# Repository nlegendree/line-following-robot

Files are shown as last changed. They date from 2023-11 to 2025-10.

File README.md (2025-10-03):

# Line Following Robot 🤖

<div align="center">

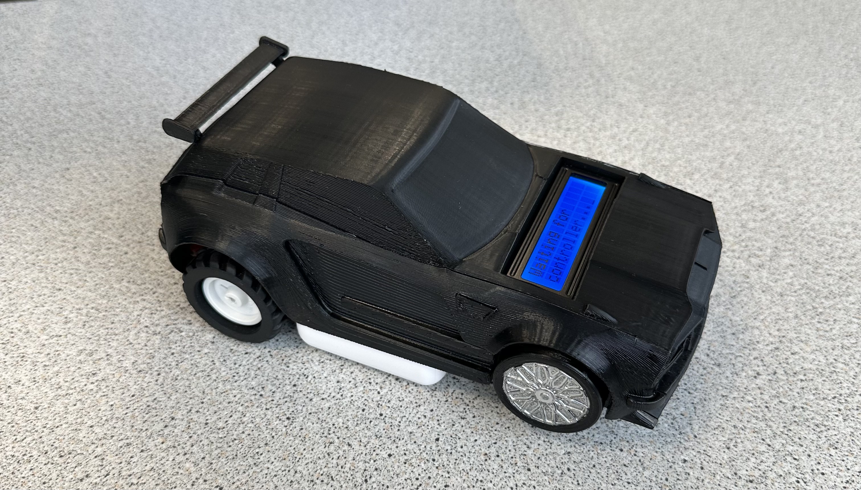
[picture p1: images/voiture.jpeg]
Robot


**Autonomous line-following robot with obstacle detection and PS5 controller support**





*INSA Rouen Normandie - Embedded Electronics Project 2023-2024*

</div>

## 📋 Table of Contents

- [About](#-about)
- [Features](#-features)
- [Hardware Components](#-hardware-components)
- [Circuit Diagram](#-circuit-diagram)
- [Software Architecture](#-software-architecture)
- [Installation](#-installation)
- [Usage](#-usage)
- [Project Structure](#-project-structure)
- [Team](#-team)

## 🎯 About

This project is an autonomous line-following robot developed as part of the **Embedded Electronics Systems** course at INSA Rouen Normandie. The robot combines infrared line detection, ultrasonic obstacle avoidance, and manual control via a PS5 controller, all housed in a custom 3D-printed Rocket League-inspired chassis.

### Key Highlights

- **Dual Control Modes**: Autonomous line-following and manual PS5 controller
- **Safety Features**: Ultrasonic distance sensor with buzzer alerts
- **Real-time Display**: LCD screen showing status and distance information
- **Custom Hardware**: 3D-printed car body designed in SolidWorks
- **Low-level Programming**: Written entirely in C using WiringPi library

## ✨ Features

### Autonomous Mode
- ✅ **Line Following**: Three TCRT5000 infrared sensors for precise line tracking
- ✅ **Intersection Detection**: Recognizes and handles T-junctions and crossroads
- ✅ **Obstacle Detection**: HC-SR04 ultrasonic sensor with 20cm stop threshold
- ✅ **Audio Alerts**: Active buzzer for obstacle warnings
- ✅ **Visual Feedback**: LCD display showing movement status and distance

### Manual Control Mode
- 🎮 **PS5 Controller Support**: Full gamepad integration via SDL2
- 🚗 **Analog Control**: Smooth acceleration and steering using triggers and joystick
- 📊 **Speed Display**: Real-time speed indicator on LCD screen
- 🔄 **Mode Switching**: Instant toggle between autonomous and manual modes

## 🔧 Hardware Components

| Component | Model | Function |
|---|---|---|
| **Microcontroller** | Raspberry Pi 4 | Main control unit |
| **Line Sensors** | TCRT5000 (×3) | Infrared line detection |
| **Distance Sensor** | HC-SR04 | Ultrasonic obstacle detection |
| **Motor Driver** | L293D | Dual H-bridge motor controller |
| **Display** | LCD 1602 I2C | Status and distance display |
| **Buzzer** | Active Buzzer | Obstacle alert |
| **Controller** | PS5 DualSense | Manual control (Bluetooth) |
| **Motors** | DC Motors (×2) | Wheel propulsion |
| **Power** | 9V Battery + External Pack | Raspberry Pi and motors |

### Component Images

<details>
<summary>View Hardware Components</summary>

<table>
<tr>
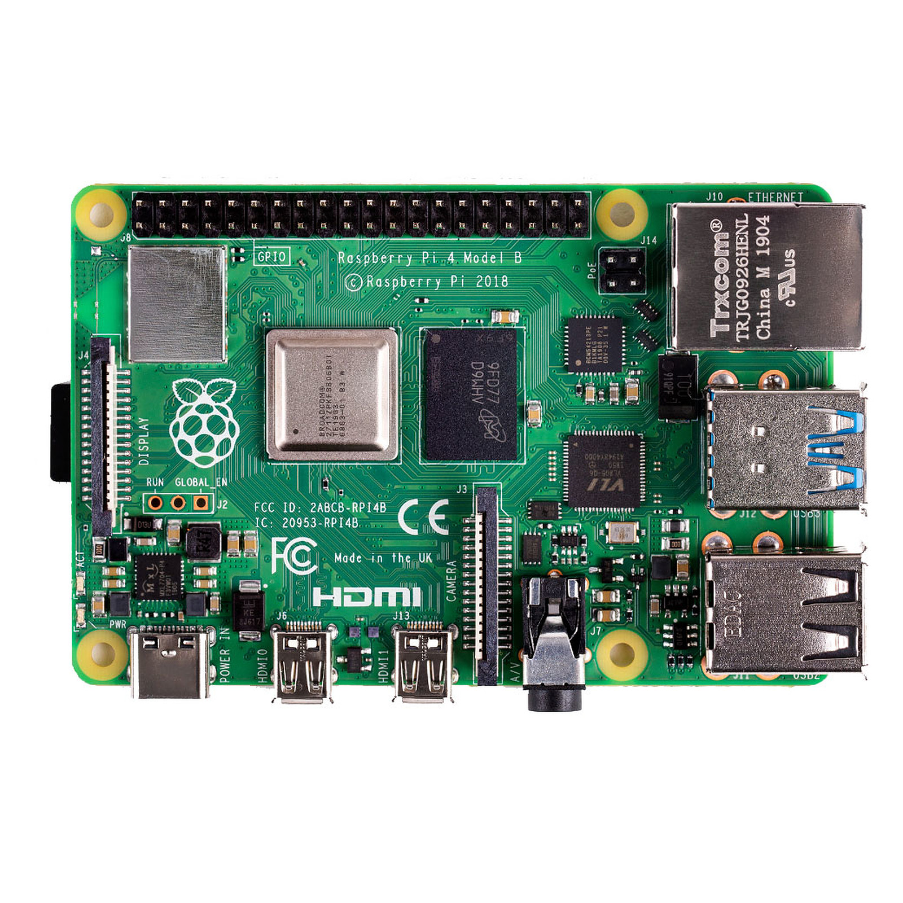
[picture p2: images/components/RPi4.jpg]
<td><br/><b>Raspberry Pi 4</b></td>
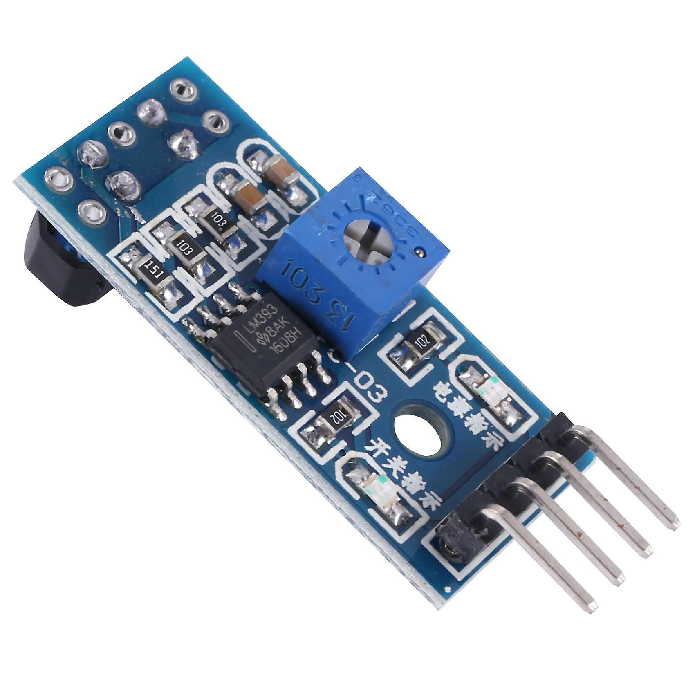
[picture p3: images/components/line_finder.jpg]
<td><br/><b>TCRT5000 Sensor</b></td>
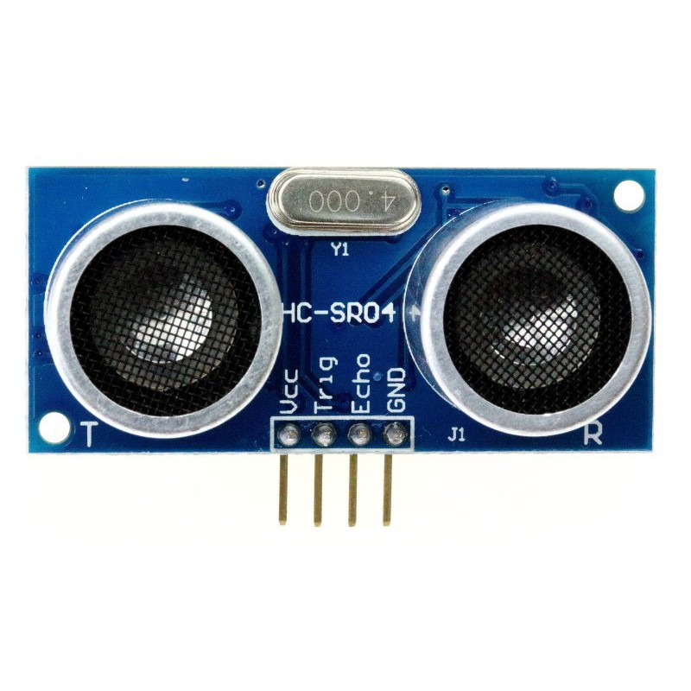
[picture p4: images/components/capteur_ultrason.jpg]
<td><br/><b>HC-SR04</b></td>
</tr>
<tr>
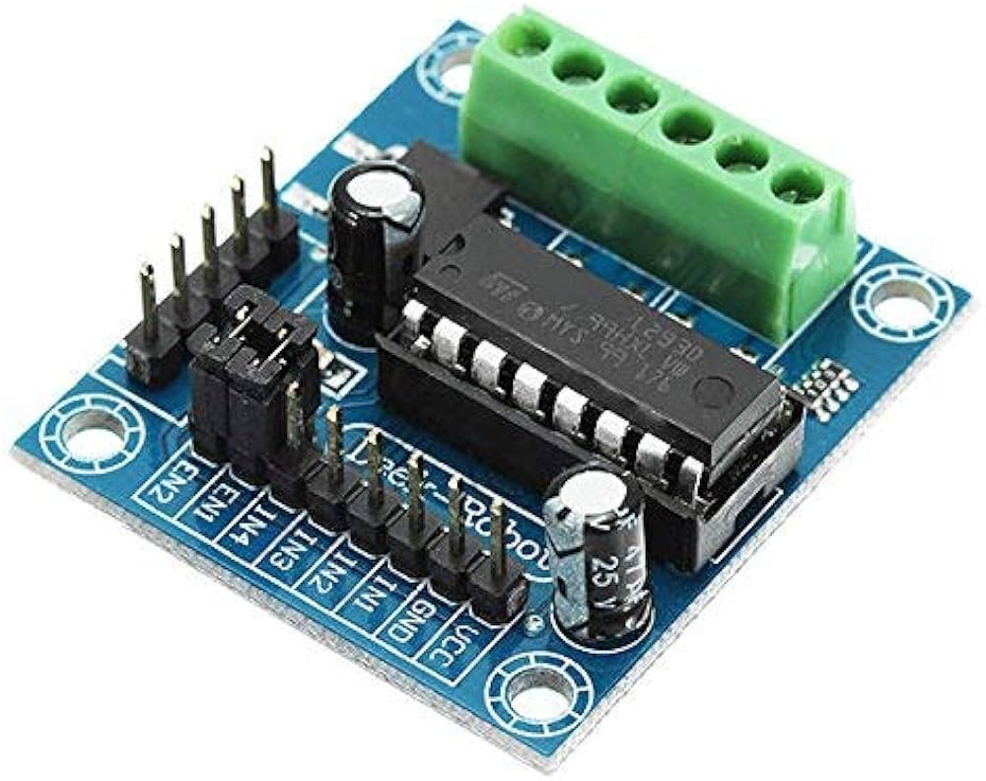
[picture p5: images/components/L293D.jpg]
<td><br/><b>L293D Driver</b></td>
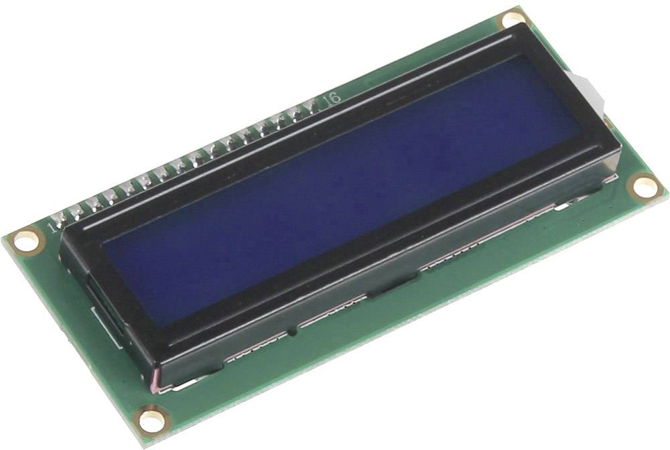
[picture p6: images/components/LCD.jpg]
<td><br/><b>LCD 1602</b></td>
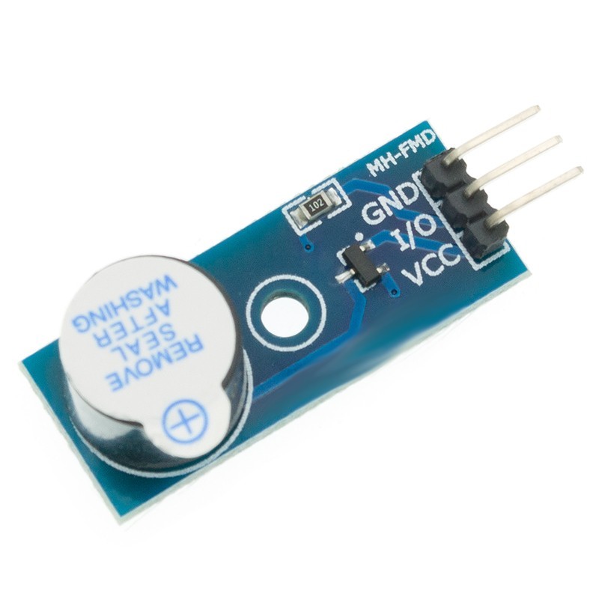
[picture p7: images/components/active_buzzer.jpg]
<td><br/><b>Active Buzzer</b></td>
</tr>
</table>

</details>

## 📐 Circuit Diagram

The complete circuit was designed using **Fritzing** and includes GPIO pin mappings for all components.

<details>
<summary>View Circuit Schematics</summary>

### Component Layout
Fritzing Diagram

### Electronic Schematic
Electronic Schematic

</details>

### GPIO Pin Configuration

```c
// Line Finder Sensors
#define PIN_LINEFINDER_LEFT    17
#define PIN_LINEFINDER_CENTER  22
#define PIN_LINEFINDER_RIGHT   10

// Ultrasonic Sensor
#define PIN_TRIG  25
#define PIN_ECHO  8

// Motor Driver (L293D)
#define PIN_EN1   13  // PWM Enable Motor 1
#define PIN_EN2   12  // PWM Enable Motor 2
#define PIN_M1A   5   // Motor 1 Direction A
#define PIN_M1B   6   // Motor 1 Direction B
#define PIN_M2A   26  // Motor 2 Direction A
#define PIN_M2B   21  // Motor 2 Direction B

// Buzzer
#define PIN_BUZZER 14
```

## 🏗️ Software Architecture

The project is structured using a modular approach with separate modules for each hardware component.

### Code Organization

```
src/
├── main.c           # Main program with event loop
├── motors.c         # Motor control (PWM, direction)
├── lineFinder.c     # Line detection logic
├── distance.c       # Ultrasonic sensor readings
├── controller.c     # PS5 gamepad handling (SDL2)
├── i2cLCD.c        # LCD display communication
└── buzzer.c        # Buzzer control

include/
├── motors.h
├── lineFinder.h
├── distance.h
├── controller.h
├── i2cLCD.h
├── buzzer.h
└── gpioPins.h      # GPIO pin definitions
```

### Key Algorithms

#### Line Following Logic

```c
// Truth table for line following
// L | C | R | Action
// --+---+---+------------------
// 0 | 0 | 0 | Keep previous state
// 0 | 0 | 1 | Turn right
// 0 | 1 | 0 | Move forward
// 0 | 1 | 1 | Move forward (intersection)
// 1 | 0 | 0 | Turn left
// 1 | 0 | 1 | Move forward (intersection)
// 1 | 1 | 0 | Move forward (intersection)
// 1 | 1 | 1 | Move forward (intersection)
```

#### PWM Motor Control

The robot uses hardware PWM with adaptive speed control based on steering angle:

```c
// Speed adjustment for turning
if (angle < 0) {  // Turning left
    leftMotorSpeed = baseSpeed * (1 - |angle| / MAX_ANGLE);
    rightMotorSpeed = baseSpeed;
} else {  // Turning right
    leftMotorSpeed = baseSpeed;
    rightMotorSpeed = baseSpeed * (1 - angle / MAX_ANGLE);
}
```

## 🚀 Installation

### Prerequisites

```bash
# Update system
sudo apt update && sudo apt upgrade

# Install required libraries
sudo apt install -y \
    build-essential \
    git \
    wiringpi \
    libsdl2-dev \
    libi2c-dev

# Enable I2C interface
sudo raspi-config
# Navigate to: Interfacing Options → I2C → Enable
```

### Building the Project

```bash
# Clone the repository
git clone git@github.com:nlegendree/line-following-robot.git
cd line-following-robot

# Compile the project
make

# The executable will be created in bin/rc
```

### Hardware Setup

1. **Connect all components** according to the Fritzing diagram
2. **Pair PS5 controller** via Bluetooth settings
3. **Calibrate line sensors** on your track surface
4. **Test motors** individually before full assembly

## 📖 Usage

### Running the Robot

```bash
# Start the program (requires sudo for GPIO access)
sudo ./bin/rc
```

### Controls

#### Autonomous Mode
- Press **Cross (×)** button to activate line-following mode
- The robot will:
  - Follow black lines automatically
  - Stop when obstacles are < 20cm away
  - Display distance on LCD when obstacles are detected
  - Sound buzzer for close obstacles

#### Manual Mode
- Press **Circle (○)** button to activate manual control
- **R2 Trigger**: Accelerate forward
- **L2 Trigger**: Reverse
- **Left Stick (horizontal)**: Steering
- **LCD Display**: Shows current speed

### Mode Indicators

| LCD Display | Meaning |
|---|---|
| `Waiting for controller...` | No controller connected |
| `Speed: XX kph` | Manual mode active |
| `Moving forward` | Line-following: going straight |
| `Turning left/right` | Line-following: adjusting direction |
| `Obstacle: XX cm` | Warning distance display |
| `Obstacle too close!` | Emergency stop (< 20cm) |

## 📁 Project Structure

```
line-following-robot/
├── bin/                    # Compiled executables
├── src/                    # C source files
│   ├── main.c
│   ├── motors.c
│   ├── lineFinder.c
│   ├── distance.c
│   ├── controller.c
│   ├── i2cLCD.c
│   └── buzzer.c
├── include/                # Header files
│   ├── motors.h
│   ├── lineFinder.h
│   ├── distance.h
│   ├── controller.h
│   ├── i2cLCD.h
│   ├── buzzer.h
│   └── gpioPins.h
├── images/                 # Project images
│   ├── components/        # Component photos
│   ├── fritzing/          # Circuit diagrams (PDF)
│   ├── solidworks/        # 3D model screenshots
│   └── voiture.jpeg       # Final robot photo
├── circuit/               # Fritzing project files
├── makefile              # Build configuration
├── LICENSE               # MIT License
└── README.md             # This file
```

## 👥 Team

This project was developed collaboratively by a **team of four engineering students** at INSA Rouen Normandie as part of the Embedded Electronics Systems course.

**Academic Year**: 2023-2024
**Institution**: [INSA Rouen Normandie](https://www.insa-rouen.fr/)

## 📄 License

This project is available under the MIT License. See [LICENSE](LICENSE) for details.

---

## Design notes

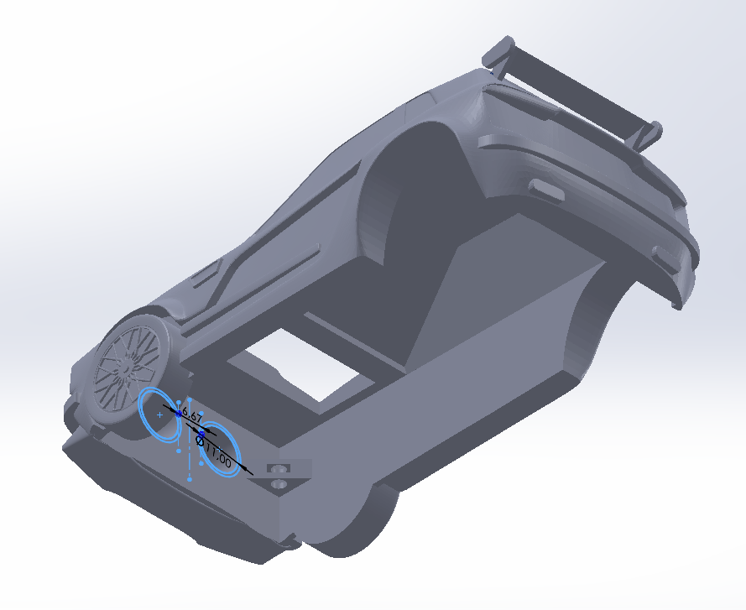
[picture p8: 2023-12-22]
images/solidworks/solidworks4.png

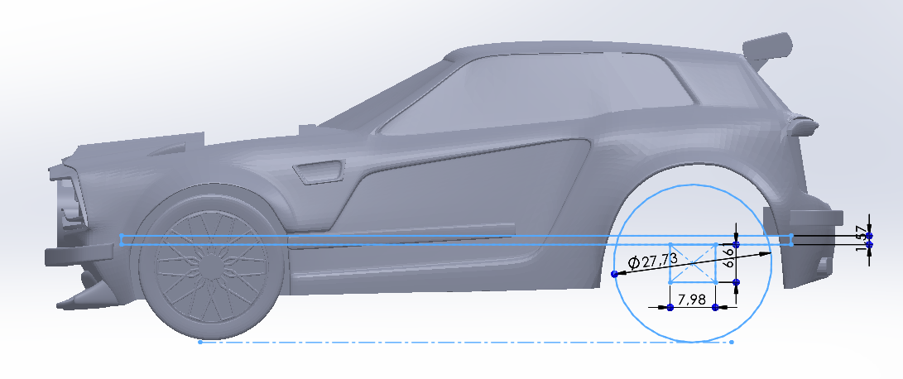
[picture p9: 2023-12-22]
images/solidworks/solidworks3.png

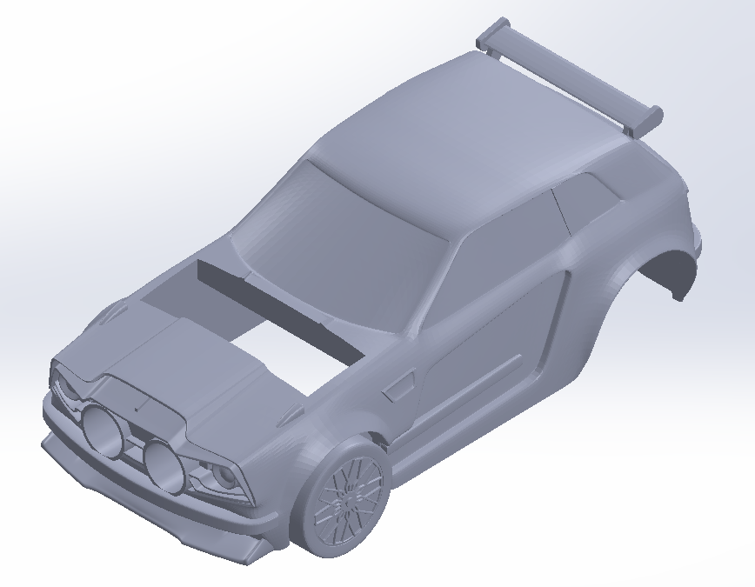
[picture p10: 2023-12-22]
images/solidworks/solidworks1.png

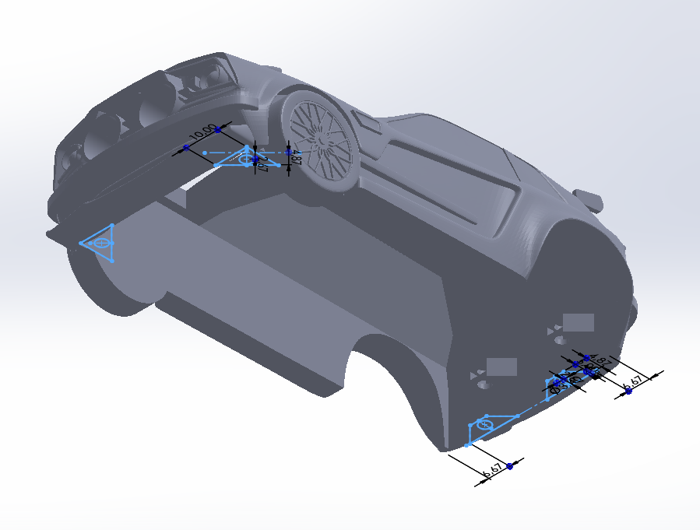
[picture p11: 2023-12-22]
images/solidworks/solidworks2.png

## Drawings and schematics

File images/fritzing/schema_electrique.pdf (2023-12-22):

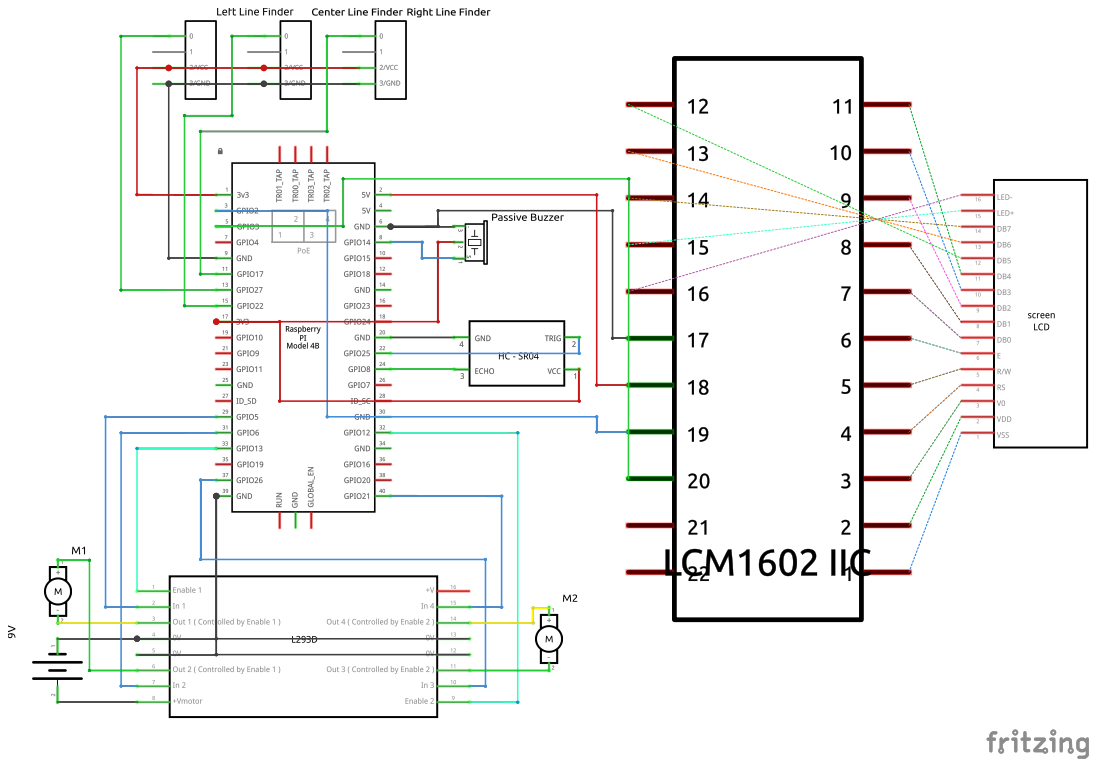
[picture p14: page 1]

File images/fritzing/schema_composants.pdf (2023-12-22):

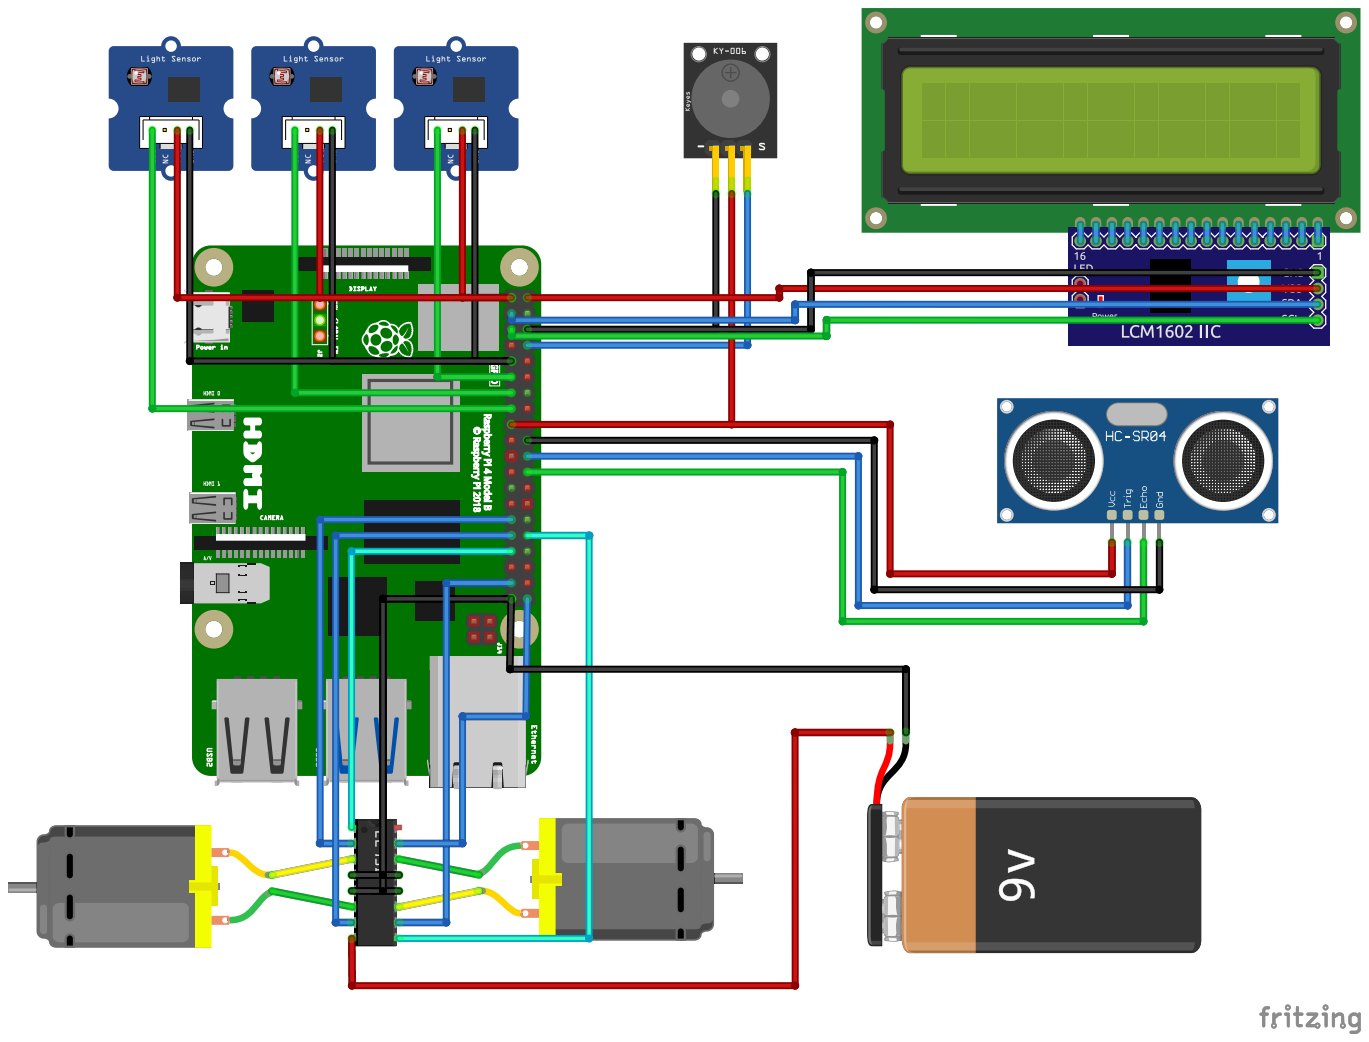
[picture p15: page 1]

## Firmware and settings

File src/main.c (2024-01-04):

#include <SDL2/SDL.h>
#include <fcntl.h>
#include <lcd.h>
#include <stdio.h>
#include <stdlib.h>
#include <string.h>
#include <wiringPi.h>

#include "buzzer.h"
#include "controller.h"
#include "distance.h"
#include "gpioPins.h"
#include "i2cLCD.h"
#include "lineFinder.h"
#include "motors.h"

#define MODE_MANUAL 0
#define MODE_LINEFINDER 1

#define FORWARD 0
#define TURN_LEFT 1
#define TURN_RIGHT 2

// Global variables used to communicate between processes
int lcd, mode, motorState, R2, L2, LX;
bool controllerConnected, nearObstacle, exitSDL;

// LCD display and distance acquisition process
PI_THREAD(lcdPrintAndGetDistance) {
    while (!exitSDL) {
        lcdClear(lcd);
        if (controllerConnected) {          // If a controller is connected
            if (mode == MODE_LINEFINDER) {  // If the robot is in line-finding mode
                int distance = getDistance();
                if (distance <= DISPLAY_DISTANCE) {   // If the distance sensor detects an obstacle
                    if (distance <= STOP_DISTANCE) {  // If an obstacle is too close to the distance sensor
                        lcdPrintf(lcd, "Obstacle too    close!");
                        nearObstacle = 1;
                    } else {  // If an obstacle is relatively close to the distance sensor
                        lcdPrintf(lcd, "Obstacle : %d cm", distance);
                        nearObstacle = 0;
                    }
                } else {  // If the distance sensor does not detect any obstacle, the LCD display shows the direction the robot is taking
                    switch (motorState) {
                        case FORWARD:
                            lcdPrintf(lcd, "Moving forward");
                            break;
                        case TURN_LEFT:
                            lcdPrintf(lcd, "Truning left");
                            break;
                        case TURN_RIGHT:
                            lcdPrintf(lcd, "Turning right");
                            break;
                    }
                    nearObstacle = 0;
                }
            } else if (mode == MODE_MANUAL) {  // If the robot is in manual mode
                lcdPrintf(lcd, "Speed : %d kph", abs((int)((R2 - L2) / 252)));
            }
        } else {  // If a controller is not connected
            lcdPrintf(lcd, "Waiting for     controller...");
        }
        delay(100);
    }
    return 0;
}

// Direction selection function in line-finding mode
void lineFinder(int lcd) {
    // Line finder sensors states update
    bool left = detectLine(PIN_LINEFINDER_LEFT);
    bool center = detectLine(PIN_LINEFINDER_CENTER);
    bool right = detectLine(PIN_LINEFINDER_RIGHT);
    printf("%d %d %d\n", left, center, right);

    // Actions based on these states
    if (nearObstacle) {  // If the distance sensor detects an obstacle
        stopMotors();
        buzzerOn();
    } else {                               // If the distance sensor does not detect any obstacle
        if (!left && !center && !right) {  // If all sensors detect a white surface, the motors keep their previous state
            switch (motorState) {
                case FORWARD:
                    LF_forward();
                    break;
                case TURN_LEFT:
                    LF_turnLeft();
                    break;
                case TURN_RIGHT:
                    LF_turnRight();
                    break;
            }
        } else if (detectIntersection(left, center, right) || center) {  // If the sensors detect an intersection or a front line, the motors move forward
            LF_forward();
            motorState = FORWARD;
        } else if (left) {  // If only the left sensor detects a line, the motors turn left
            LF_turnLeft();
            motorState = TURN_LEFT;
        } else if (right) {  // If only the right sensor detects a line, the motors turn right
            LF_turnRight();
            motorState = TURN_RIGHT;
        }
        buzzerOff();
    }
}

// Robot control function in manual-control mode
void manualControl(int lcd, SDL_GameController *controller) {
    // Triggers and axes states update
    R2 = triggerValue(controller, SDL_CONTROLLER_AXIS_TRIGGERRIGHT);
    L2 = triggerValue(controller, SDL_CONTROLLER_AXIS_TRIGGERLEFT);
    LX = axisValue(controller, SDL_CONTROLLER_AXIS_LEFTX);

    // Actions based on these states
    if (R2 >= L2) {  // If the acceleration trigger is pressed further in than the reverse trigger
        forward(R2 - L2, LX);
    } else {  // If the reverse trigger is pressed further in than the acceleration trigger
        backward(L2 - R2, LX);
    }
}

// Main function
int main(int argc, char *argv[]) {
    // WiringPi Initialization
    wiringPiSetupGpio();

    // LCD Initialization
    lcd = initLCD();

    // Controller Initialization
    SDL_GameController *controller = initController();

    // Motors Initialization
    initMotors();

    // Line-Finder Initialization
    initLineFinder();

    // Line-Finder Initialization
    initDistanceSensor();

    // Buzzer Initialization
    initBuzzer();
    buzzerOff();

    // LCD and Distance Sensor Thread Creation
    piThreadCreate(lcdPrintAndGetDistance);

    // Main loop
    SDL_Event event;
    exitSDL = 0;
    controllerConnected = 0;
    mode = MODE_MANUAL;
    nearObstacle = 0;
    motorState = FORWARD;
    while (!exitSDL) {
        SDL_PollEvent(&event);
        if (event.type == SDL_QUIT)  // Checks if the user wants to exit the program
            exitSDL = 1;
        if (event.cdevice.type == SDL_CONTROLLERDEVICEADDED && !controllerConnected) {  // Checks if a controller has been connected
            controller = SDL_GameControllerOpen(0);
            controllerConnected = 1;
        }
        if (event.cdevice.type == SDL_CONTROLLERDEVICEREMOVED && controllerConnected) {  // Checks if a controller has been disconnected
            SDL_GameControllerClose(controller);
            stopMotors();
            mode = MODE_MANUAL;
            buzzerOff();
            controllerConnected = 0;
        }
        if (controllerConnected) {
            if (buttonIsBeingPressed(controller, SDL_CONTROLLER_BUTTON_A))  // Press CROSS to enter Line-Finder Mode
                mode = MODE_LINEFINDER;
            else if (buttonIsBeingPressed(controller, SDL_CONTROLLER_BUTTON_B)) {  // Press CIRCLE to leave Line-Finder Mode
                buzzerOff();
                mode = MODE_MANUAL;
                motorState = FORWARD;
            }

            if (mode == MODE_LINEFINDER)  // Executes the line-following mode
                lineFinder(lcd);
            else if (mode == MODE_MANUAL)  // Executes the manual mode
                manualControl(lcd, controller);
        }
    }

    // Actions performed when the program exits
    buzzerOff();
    SDL_Quit();

    return EXIT_SUCCESS;
}

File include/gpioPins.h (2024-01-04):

#ifndef __GPIO_PIN__
#define __GPIO_PIN__

#define PIN_BUZZER              14

#define PIN_LINEFINDER_LEFT     17
#define PIN_LINEFINDER_CENTER   22
#define PIN_LINEFINDER_RIGHT    10

#define PIN_TRIG                25
#define PIN_ECHO                8

#define PIN_EN1                 13
#define PIN_EN2                 12

#define PIN_M1A                 5
#define PIN_M1B                 6
#define PIN_M2A                 26
#define PIN_M2B                 21

#endif

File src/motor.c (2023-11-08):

#include <wiringPi.h>

// Définir les numéros de broches GPIO utilisées pour le contrôle du moteur
#define M1A 18  // Broche GPIO pour le contrôle du moteur (IN1)
#define M1B 12 // Broche GPIO pour le contrôle du moteur (IN2)
#define M2B 19  // Broche GPIO pour le contrôle du moteur (IN2)
#define M2A 13  // Broche GPIO pour le contrôle du moteur (IN2)

// Initialisation de la bibliothèque WiringPi
void init() {
    pinMode(M1A, PWM_OUTPUT);
	pinMode(M1B, PWM_OUTPUT);
	pinMode(M2A, PWM_OUTPUT);
	pinMode(M2B, PWM_OUTPUT);
    pwmSetMode(PWM_MODE_MS);
    pwmSetClock(400);    // Réglage de la fréquence PWM
    pwmSetRange(1024);   // Réglage de la plage PWM (0-1024)
}

// Fonction pour faire avancer le moteur
void forward(int R2) {
    digitalWrite(M1B, LOW);
    digitalWrite(M2B, LOW);
    pwmWrite(M1A, (int)(R2*1024)/256);
    pwmWrite(M2A, (int)(R2*1024)/256);
}

// Fonction pour faire reculer le moteur
void reverse() {
    digitalWrite(MOTOR_PIN1, LOW);
    digitalWrite(MOTOR_PIN2, HIGH);
    pwmWrite(PWM_PIN, 512);  // 50% de puissance
}

// Fonction pour arrêter le moteur
void stop() {
    digitalWrite(MOTOR_PIN1, LOW);
    digitalWrite(MOTOR_PIN2, LOW);
    pwmWrite(PWM_PIN, 0);  // PWM à zéro pour arrêter le moteur
}

void turnRight(int angle) {
    
   

}



int main() {
	wiringPiSetupGpio();
    init();  // Initialisation
	while(1) {
		forward(255);
	}


    return 0;
}

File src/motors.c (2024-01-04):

#include "motors.h"

#include <math.h>
#include <wiringPi.h>

#include "controller.h"
#include "gpioPins.h"

// Motors initialization
void initMotors() {
    pinMode(PIN_M1A, OUTPUT);
    pinMode(PIN_M1B, OUTPUT);
    pinMode(PIN_M2A, OUTPUT);
    pinMode(PIN_M2B, OUTPUT);
    pinMode(PIN_EN1, PWM_OUTPUT);
    pinMode(PIN_EN2, PWM_OUTPUT);

    pwmSetMode(PWM_MODE_MS);
    pwmSetClock(PWM_CLOCK);
    pwmSetRange(PWM_RANGE);
}

// Function to make the robot move forward with a specified speed and steering angle
void forward(int speed, int angle) {
    // Pins setting to make motors move forward
    digitalWrite(PIN_M1A, HIGH);
    digitalWrite(PIN_M2A, HIGH);
    digitalWrite(PIN_M1B, LOW);
    digitalWrite(PIN_M2B, LOW);

    float coeffSpeed = (float)speed / MAX_TRIGGER;
    if (angle <= 0) {  // If the user turns left, only the speed of the left motor depends on the angle of rotation
        float coeffAngle = (float)(MIN_AXIS - angle) / MIN_AXIS;
        pwmWrite(PIN_EN1, (int)round(coeffAngle * coeffSpeed * PWM_RANGE));
        pwmWrite(PIN_EN2, (int)round(coeffSpeed * PWM_RANGE));
    } else {  // If the user turns right, only the speed of the right motor depends on the angle of rotation
        float coeffAngle = (float)(MAX_AXIS - angle) / MAX_AXIS;
        pwmWrite(PIN_EN1, (int)round(coeffSpeed * PWM_RANGE));
        pwmWrite(PIN_EN2, (int)round(coeffAngle * coeffSpeed * PWM_RANGE));
    }
}

// Function to make the robot move backward with a specified speed and steering angle
void backward(int speed, int angle) {
    // Pins setting to make motors move backward
    digitalWrite(PIN_M1A, LOW);
    digitalWrite(PIN_M2A, LOW);
    digitalWrite(PIN_M1B, HIGH);
    digitalWrite(PIN_M2B, HIGH);

    float coeffSpeed = (float)speed / MAX_TRIGGER;
    if (angle <= 0) {  // If the user turns left, only the speed of the left motor depends on the angle of rotation
        float coeffAngle = (float)(MIN_AXIS - angle) / MIN_AXIS;
        pwmWrite(PIN_EN1, (int)round(coeffAngle * coeffSpeed * PWM_RANGE));
        pwmWrite(PIN_EN2, (int)round(coeffSpeed * PWM_RANGE));
    } else {  // If the user turns right, only the speed of the right motor depends on the angle of rotation
        float coeffAngle = (float)(MAX_AXIS - angle) / MAX_AXIS;
        pwmWrite(PIN_EN1, (int)round(coeffSpeed * PWM_RANGE));
        pwmWrite(PIN_EN2, (int)round(coeffAngle * coeffSpeed * PWM_RANGE));
    }
}

// Function to stop the motors
void stopMotors() {
    pwmWrite(PIN_EN1, 0);
    pwmWrite(PIN_EN2, 0);
}

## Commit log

2023-10-25 add circuit
    [Projet_ELEC.fzz]
2023-10-30 I2C + LCD
2023-10-30 avancement circuit
    [Projet_ELEC.fzz]
2023-10-31 circuit partie schematique
    [Projet_ELEC.fzz]
2023-10-31 Modification sur la gestion des obstacles
2023-11-01 ajout de suiveurDeLigne.c et line.h
2023-11-08 ajout buzzer circuit
    [Projet_ELEC.fzz]
2023-11-08 ajout motor.c
2023-11-08 motors no rotation
2023-11-09 correction motors
2023-11-13 page de garde + intro
2023-11-14 make + motors_1 (test)
2023-11-15 circuit avancements
    [Projet_ELEC.fzz]
2023-11-15 circuit fini
    [Projet_ELEC.fzz]
2023-11-16 arrondi plutot que troncature
2023-11-17 test SDL plutot que evdev
2023-11-25 correction liens entre i2c et lcd
    [Projet_ELEC.fzz]
2023-12-07 test sans prise de distance
2023-12-07 test distance thread
2023-12-07 stop motors when controller disconnected
2023-12-10 Ajout de la liste des tâches
2023-12-11 ajout de texte
2023-12-11 ajout du logo de l'insa
2023-12-11 changement gpio linefinder de droite
2023-12-17 ajout de photos
2023-12-22 circuit pdf
    [Projet_ELEC.fzz]
2023-12-22 circuit pdf schem
    [Projet_ELEC.fzz]
2023-12-23 Saut de ligne auto minted
